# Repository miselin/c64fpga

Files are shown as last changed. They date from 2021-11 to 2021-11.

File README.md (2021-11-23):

# FPGA Boards for Commodore 64

These boards connect to the User and Expansion ports of the Commmodore 64 and
break the pins out onto the I/O in the [Mercury FPGA](https://www.micro-nova.com/mercury)
development board.

This is pin-compatible with either the Mercury or the Mercury 2, the latter
using a more modern Artix-7 FPGA than the Mercury's Spartan 3A.

## Cartridge Board

This board requires two 4-channel I2C-safe bidirectional logic level shifters
as the cartridge pinout has 44 pins, but the Mercury board only has 30 5V-tolerant
GPIO pins. The level shifter ensures the 5V TTL signals from the Commodore 64
are shifted down to 3.3V for the FPGA direct I/O pins.

These can be [found on Adafruit](https://www.adafruit.com/product/757).

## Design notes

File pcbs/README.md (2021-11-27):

# PCB Designs

This directory contains KiCad projects for the PCB designs
associated with the project.

`cartridge_mercury1` contains the PCB schematic to support the original
[Mercury FPGA board](https://www.micro-nova.com/mercury). This version
of the Mercury only has 30 5V-tolerant GPIOs, which means level shifters
are necessary to bring the Commodore 64's 5V TTL down to 3.3V to interface
with the FPGA I/O pins.

The [Mercury 2 FPGA board](https://www.micro-nova.com/mercury-2) on the
other hand supports 40 5V-tolerant GPIOs, which makes the PCB simpler and
does not require extra level shifting. A design to take advantage of this
is in the `cartridge_mercury2` directory.

There is no current design in progress that integrates the FPGA directly
without utilizing an additional product.

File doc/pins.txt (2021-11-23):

User Port
=========

24 pins. J2 connector. 3.96mm pitch, expects 1.57mm thick PCBs.

Pin Name    Description
1   GND     Ground
2   +5V     +5 VDC (100 mA max)
3   /RESET  Reset, will force a cold start. Also a reset output for devices.
4   CNT1    Counter 1, from CIA #1
5   SP1     Serial Port 1, from CIA #1
6   CNT2    Counter 2, from CIA #2
7   SP2     Serial port 2, from CIA #2
8   /PC2    Handshaking line, from CIA #2
9   ATN     Serial attention in
10  9VAC    9 VAC (+ phase) (100 mA max)
11  9VAC    9 VAC (- phase) (100 mA max)
12  GND     Ground
A   GND     Ground
B   /FLAG2  Flag 2
C   PB0     Data 0
D   PB1     Data 1
E   PB2     Data 2
F   PB3     Data 3
H   PB4     Data 4
J   PB5     Data 5
K   PB6     Data 6
L   PB7     Data 7
M   PA2     PA2
N   GND     Ground

- 4x GND
- 1x 5 VDC
- 2x 9 VAC (two phases)
- 15x IO

Mapping:
- 5 VDC => Mercury 5 VDC input
- GND => Ground network
- IO => Mercury 5V-tolerant GPIO

Expansion Port
==============

44 pins. 2.54mm pitch (0.1"). 2-row edge (both sides of PCB).

- 2x 5 VAC
- 4x GND
- 38x IO (two clocks, 36 IO pins)

Mapping:
- 5 VDC => Mercury 5 VDC input
- GND => Ground network
- 30x IO => Mercury 5V-tolerant GPIO
- 8x IO (2 clocks, 6 data pins) => Level Shifters + High-Speed IO

todo: decide what goes on high-speed (9 total pins)

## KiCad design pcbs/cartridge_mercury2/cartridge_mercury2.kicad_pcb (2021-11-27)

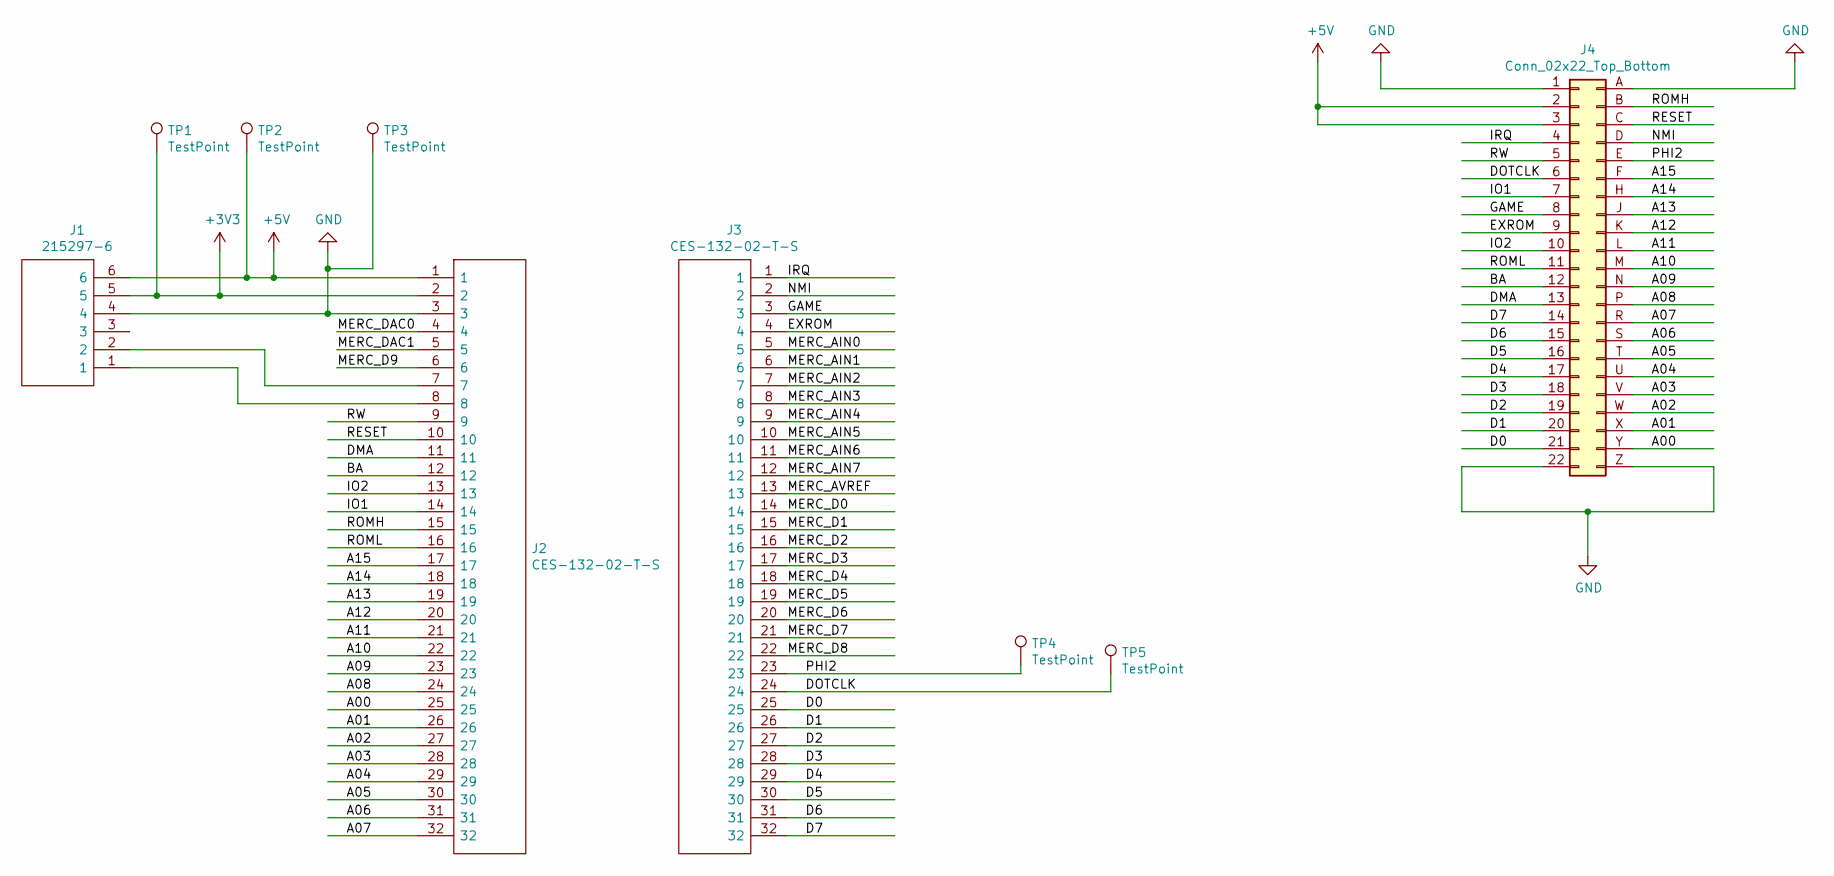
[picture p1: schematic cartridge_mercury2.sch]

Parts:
J1: 215297-6; 2152976; Mouser Part Number 571-215297-6
J2, J3: CES-132-02-T-S; CES-132-XX-Y-S; Manufacturer_Part_Number CES-132-02-T-S
J4: Conn_02x22_Top_Bottom; C64-Cart
TP1, TP2, TP3, TP4, TP5: TestPoint; TestPoint_THTPad_D1.5mm_Drill0.7mm

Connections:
+3V3: J1.5, J2.2, TP1.1
+5V: J1.6, J2.1, J4.2, J4.3, TP2.1
/A00: J2.25, J4.Y (Pin_43)
/A01: J2.26, J4.X (Pin_42)
/A02: J2.27, J4.W (Pin_41)
/A03: J2.28, J4.V (Pin_40)
/A04: J2.29, J4.U (Pin_39)
/A05: J2.30, J4.T (Pin_38)
/A06: J2.31, J4.S (Pin_37)
/A07: J2.32, J4.R (Pin_36)
/A08: J2.24, J4.P (Pin_35)
/A09: J2.23, J4.N (Pin_34)
/A10: J2.22, J4.M (Pin_33)
/A11: J2.21, J4.L (Pin_32)
/A12: J2.20, J4.K (Pin_31)
/A13: J2.19, J4.J (Pin_30)
/A14: J2.18, J4.H (Pin_29)
/A15: J2.17, J4.F (Pin_28)
/BA: J2.12, J4.12
/D0: J3.25, J4.21
/D1: J3.26, J4.20
/D2: J3.27, J4.19
/D3: J3.28, J4.18
/D4: J3.29, J4.17
/D5: J3.30, J4.16
/D6: J3.31, J4.15
/D7: J3.32, J4.14
/DMA: J2.11, J4.13
/DOTCLK: J3.24, J4.6, TP5.1
/EXROM: J3.4, J4.9
/GAME: J3.3, J4.8
/IO1: J2.14, J4.7
/IO2: J2.13, J4.10
/IRQ: J3.1, J4.4
/MERC_AIN0: J3.5
/MERC_AIN1: J3.6
/MERC_AIN2: J3.7
/MERC_AIN3: J3.8
/MERC_AIN4: J3.9
/MERC_AIN5: J3.10
/MERC_AIN6: J3.11
/MERC_AIN7: J3.12
/MERC_AVREF: J3.13
/MERC_D0: J3.14
/MERC_D1: J3.15
/MERC_D2: J3.16
/MERC_D3: J3.17
/MERC_D4: J3.18
/MERC_D5: J3.19
/MERC_D6: J3.20
/MERC_D7: J3.21
/MERC_D8: J3.22
/MERC_D9: J2.6
/MERC_DAC0: J2.4
/MERC_DAC1: J2.5
/NMI: J3.2, J4.D (Pin_26)
/PHI2: J3.23, J4.E (Pin_27), TP4.1
/RESET: J2.10, J4.C (Pin_25)
/ROMH: J2.15, J4.B (Pin_24)
/ROML: J2.16, J4.11
/RW: J2.9, J4.5
GND: J1.4, J2.3, J4.1, J4.22, J4.A (Pin_23), J4.Z (Pin_44), TP3.1
unnamed: J1.1, J2.8
unnamed: J1.2, J2.7

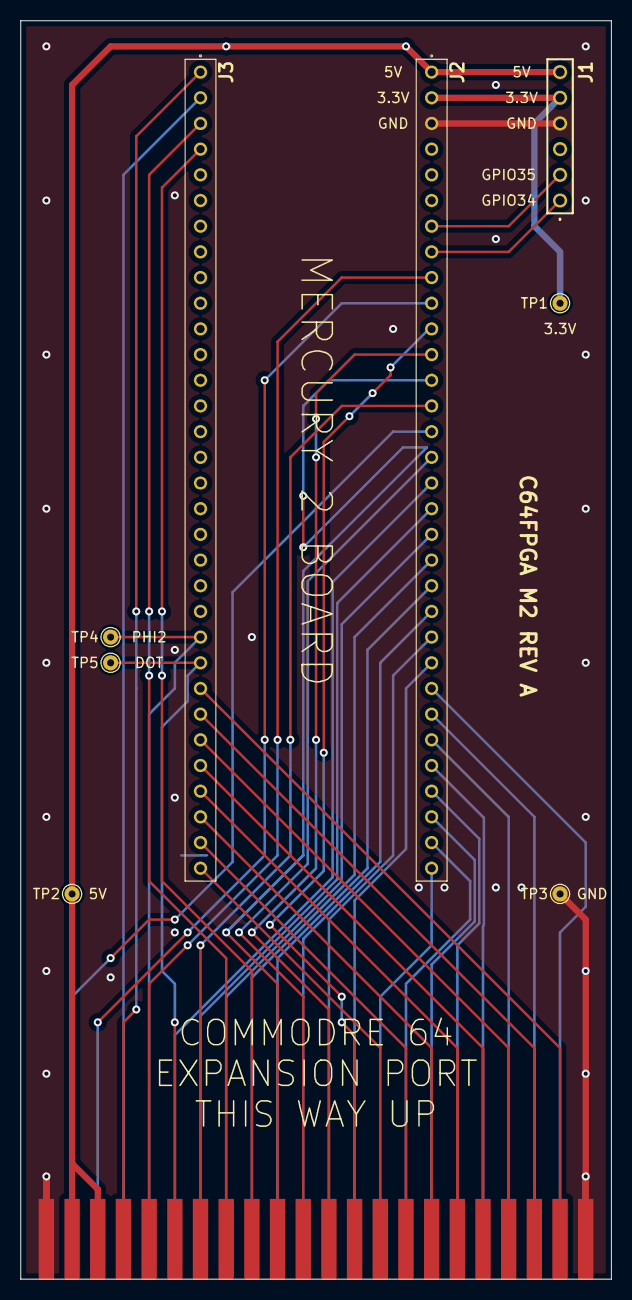
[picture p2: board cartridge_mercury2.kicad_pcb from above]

Board: 2 copper layers, 58.4 x 124.5 mm, 9 parts (0 on the bottom side), 43 nets.

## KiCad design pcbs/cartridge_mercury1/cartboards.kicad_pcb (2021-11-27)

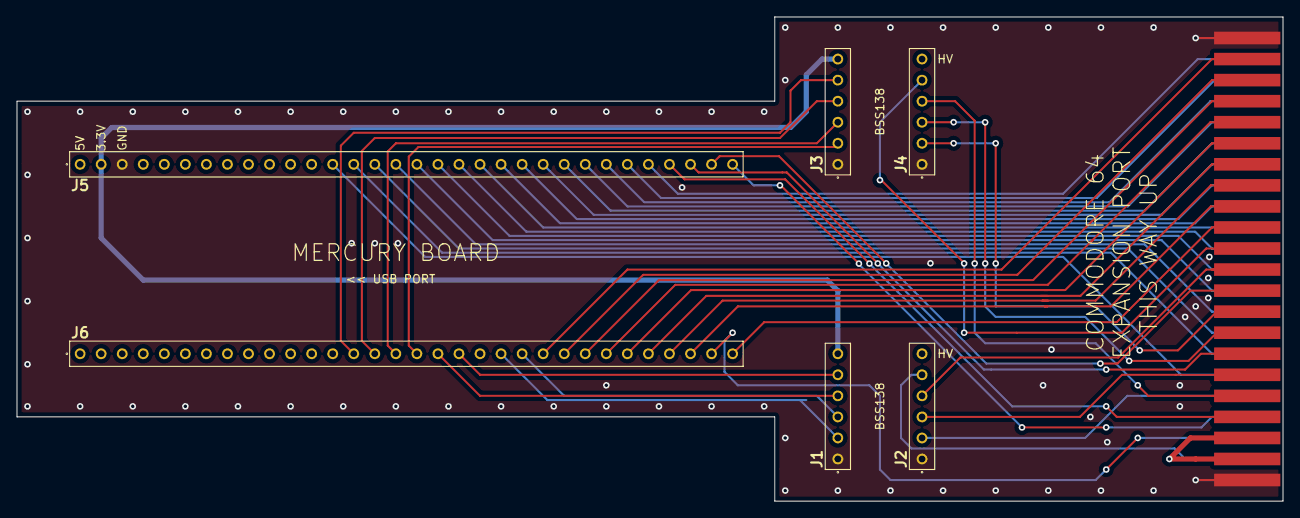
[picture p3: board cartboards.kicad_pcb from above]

Board: 4 copper layers, 152.8 x 58.4 mm, 7 parts (0 on the bottom side), 49 nets.

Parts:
C64: Conn_02x22_Counter_Clockwise; C64-Cart
J1, J2, J3, J4: CES-106-01-T-S; CES-106-XX-Y-S
J5, J6: CES-132-02-T-S; CES-132-XX-Y-S

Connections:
+3V3: J1.6, J3.6, J5.2
/CLK0: J1.2, J6.21
/CLK1: J1.3, J6.22
/DATA0: C64.21, J6.23
/DATA1: C64.20, J6.24
/DATA2: C64.19, J6.25
/DATA3: C64.18, J6.26
/DATA4: C64.17, J6.27
/DATA5: C64.16, J6.28
/DATA6: C64.15, J6.29
/DATA7: C64.14, J6.30
/DIO0: J3.5, J6.14
/DIO1: J3.4, J6.15
/DIO2: J3.3, J6.16
/DIO3: J3.2, J6.17
/DIO4: J1.4, J6.18
/DIO5: J1.5, J6.19
C64_1_GND: C64.1, C64.22, C64.A, C64.Z, J1.1, J2.1, J3.1, J4.1, J5.3
C64_2_5V: C64.2, C64.3, J2.6, J4.6, J5.1
C64_4_IRQ: C64.4, J5.29
C64_5_RW: C64.5, J4.4
C64_6_DOTCLK: C64.6, J2.3
C64_7_IO1: C64.7, J5.30
C64_8_GAME: C64.8, J4.3
C64_9_EXROM: C64.9, J4.2
C64_10_IO2: C64.10, J5.31
C64_11_ROML: C64.11, J2.4
C64_12_BA: C64.12, J4.5
C64_13_DMA: C64.13, J6.32
C64_B_ROMH: C64.B, J2.5
C64_C_RESET: C64.C, J6.31
C64_D_NMI: C64.D, J5.32
C64_E_PHI2: C64.E, J2.2
C64_F_A15: C64.F, J5.13
C64_H_A14: C64.H, J5.14
C64_J_A13: C64.J, J5.15
C64_K_A12: C64.K, J5.16
C64_L_A11: C64.L, J5.17
C64_M_A10: C64.M, J5.18
C64_N_A9: C64.N, J5.19
C64_P_A8: C64.P, J5.20
C64_R_A7: C64.R, J5.21
C64_S_A6: C64.S, J5.22
C64_T_A5: C64.T, J5.23
C64_U_A4: C64.U, J5.24
C64_V_A3: C64.V, J5.25
C64_W_A2: C64.W, J5.26
C64_X_A1: C64.X, J5.27
C64_Y_A0: C64.Y, J5.28

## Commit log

2021-11-27 Tweak trace width for power in schematics
    [cartboards.kicad_pcb, cartboards.sch, levelshift.sch]
2021-11-27 Rename PCB design directory to prep for second design
    [cartboards.kicad_pcb, cartboards.sch, file619D703E.sch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]
2021-11-27 Add FPGA daughterboard for Mercury-2 board
    [cartridge_mercury2.kicad_pcb, cartridge_mercury2.sch]
